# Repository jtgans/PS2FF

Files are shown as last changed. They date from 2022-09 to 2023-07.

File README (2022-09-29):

This is a simple board to handle exposing of the modern IBM PS/2 media sense
floppy disk controller such that it can be faked out on the controller side.

IOW, FlashFloppy (and by extension Gotek flash-based floppy drives) currently
cannot handle the advanced media sensing back to the PS/2 host controller. This
adapter exposes those media sense pins so that we can "fake" the media report
type to the host controller.

The board has been fabbed via OshPark, and is available here:
https://oshpark.com/shared_projects/WMa6Bw9U

The BoM was picked from DigiKey parts, and is available here:
http://www.digikey.com/short/2n20v9zv

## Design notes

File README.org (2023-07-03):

* PS/2 to FlashFloppy Media Sense Adapter

NOTE: This is still under development and does not work. Please don't assemble until revision C.

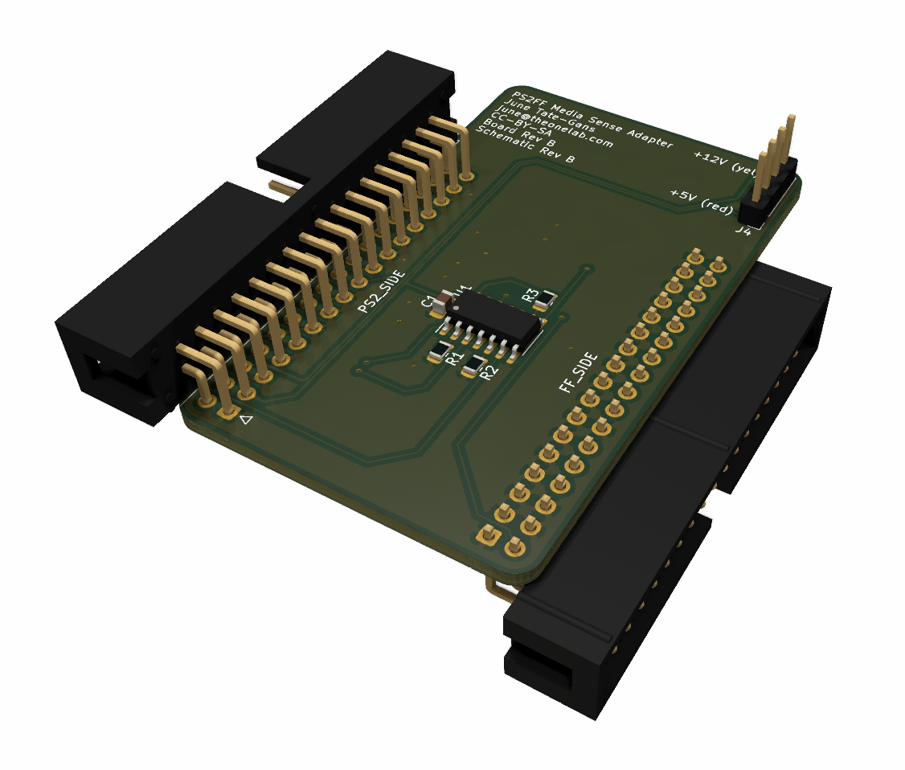
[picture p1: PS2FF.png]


This is a simple board to handle exposing of the modern IBM PS/2 media sense
floppy disk controller such that it can be faked out on the controller side.

IOW, FlashFloppy (and by extension Gotek flash-based floppy drives) currently
cannot handle the advanced media sensing back to the PS/2 host controller. This
adapter exposes those media sense pins so that we can "fake" the media report
type to the host controller.

The board has been fabbed via OshPark, and is available here:
https://oshpark.com/shared_projects/C5xEJw8V

The BoM was picked from DigiKey parts, and is available here:
https://www.digikey.com/short/q1v7w5mt

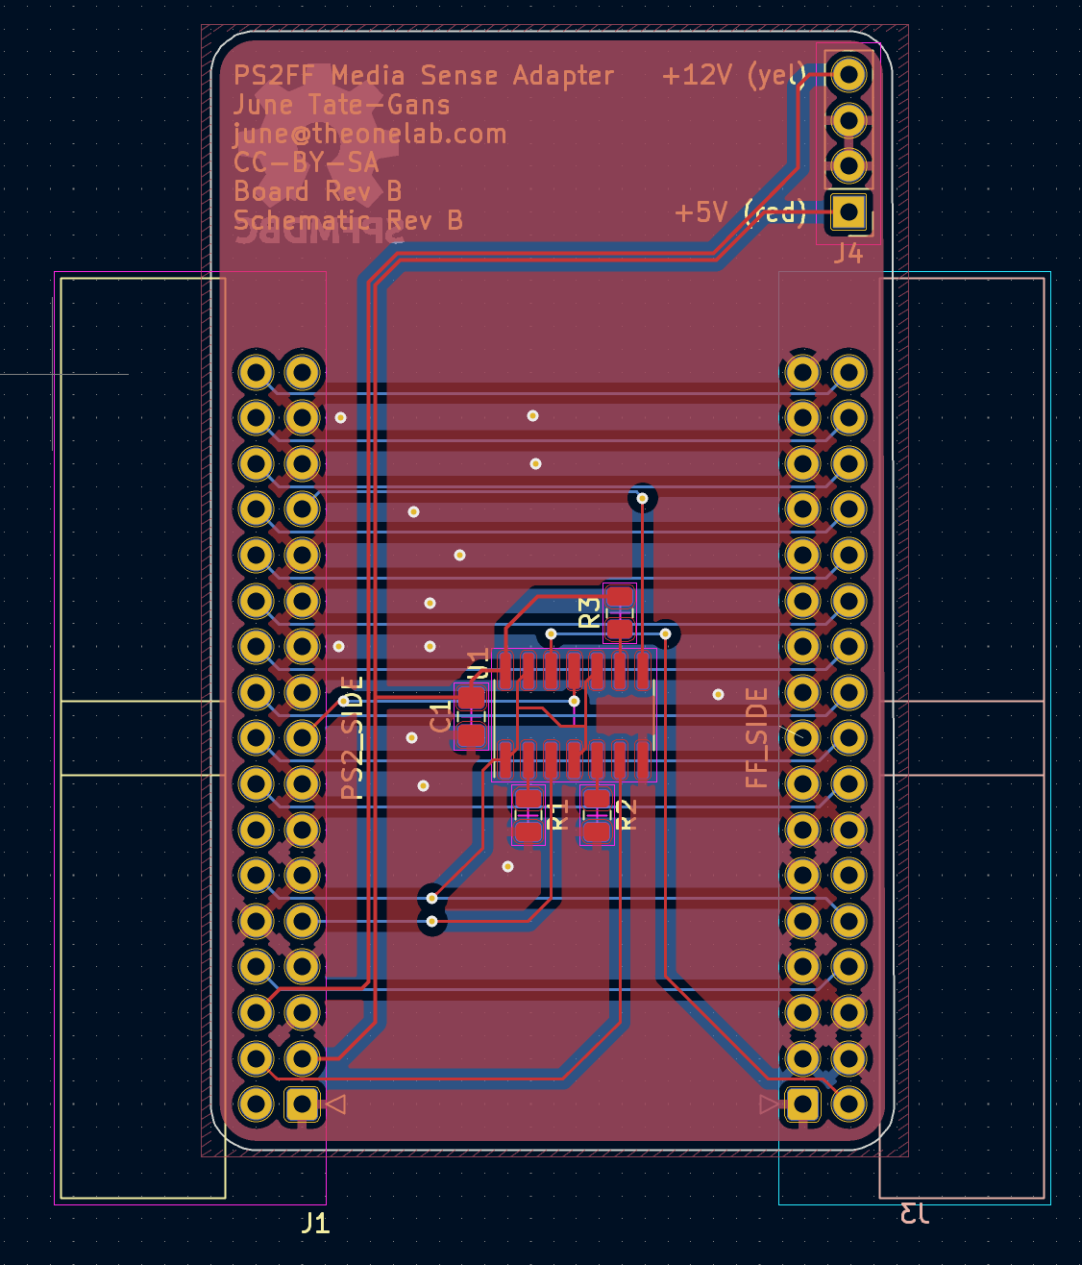
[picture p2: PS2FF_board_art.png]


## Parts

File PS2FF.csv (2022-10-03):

Source: | /Users/jtgans/Documents/Boards/PS2FF/PS2FF.kicad_sch
Date: | Monday, October 03, 2022 at 02:14:18 PM
Tool: | Eeschema (6.0.7-1)-1
Generator: | /Applications/KiCad/KiCad.app/Contents/SharedSupport/plugins/bom_csv_grouped_by_value_with_fp.py
Component Count: | 8
Ref | Qnty | Value | Cmp name | Footprint | Description | Vendor
C1, | 1 | 10pF | C_Small | Capacitor_SMD:C_0805_2012Metric_Pad1.18x1.45mm_HandSolder | Unpolarized capacitor, small symbol
J1, | 1 | PS2_SIDE | Conn_02x17_Odd_Even_1 | Connector_IDC:IDC-Header_2x17_P2.54mm_Horizontal | Generic connector, double row, 02x17, odd/even pin numbering scheme (row 1 odd numbers, row 2 even numbers), script generated (kicad-library-utils/schlib/autogen/connector/)
J3, | 1 | FF_SIDE | Conn_02x17_Odd_Even | Connector_IDC:IDC-Header_2x17_P2.54mm_Horizontal | Generic connector, double row, 02x17, odd/even pin numbering scheme (row 1 odd numbers, row 2 even numbers), script generated (kicad-library-utils/schlib/autogen/connector/)
J4, | 1 | POWER | Conn_01x04 | Connector_PinHeader_2.54mm:PinHeader_1x04_P2.54mm_Vertical | Generic connector, single row, 01x04, script generated (kicad-library-utils/schlib/autogen/connector/)
R1, R2, R3, | 3 | 1K | R_Small_US | Resistor_SMD:R_0805_2012Metric | Resistor, small US symbol
U1, | 1 | 74LS125 | 74LS125 | Package_SO:SOIC-14_3.9x8.7mm_P1.27mm | Quad buffer 3-State outputs

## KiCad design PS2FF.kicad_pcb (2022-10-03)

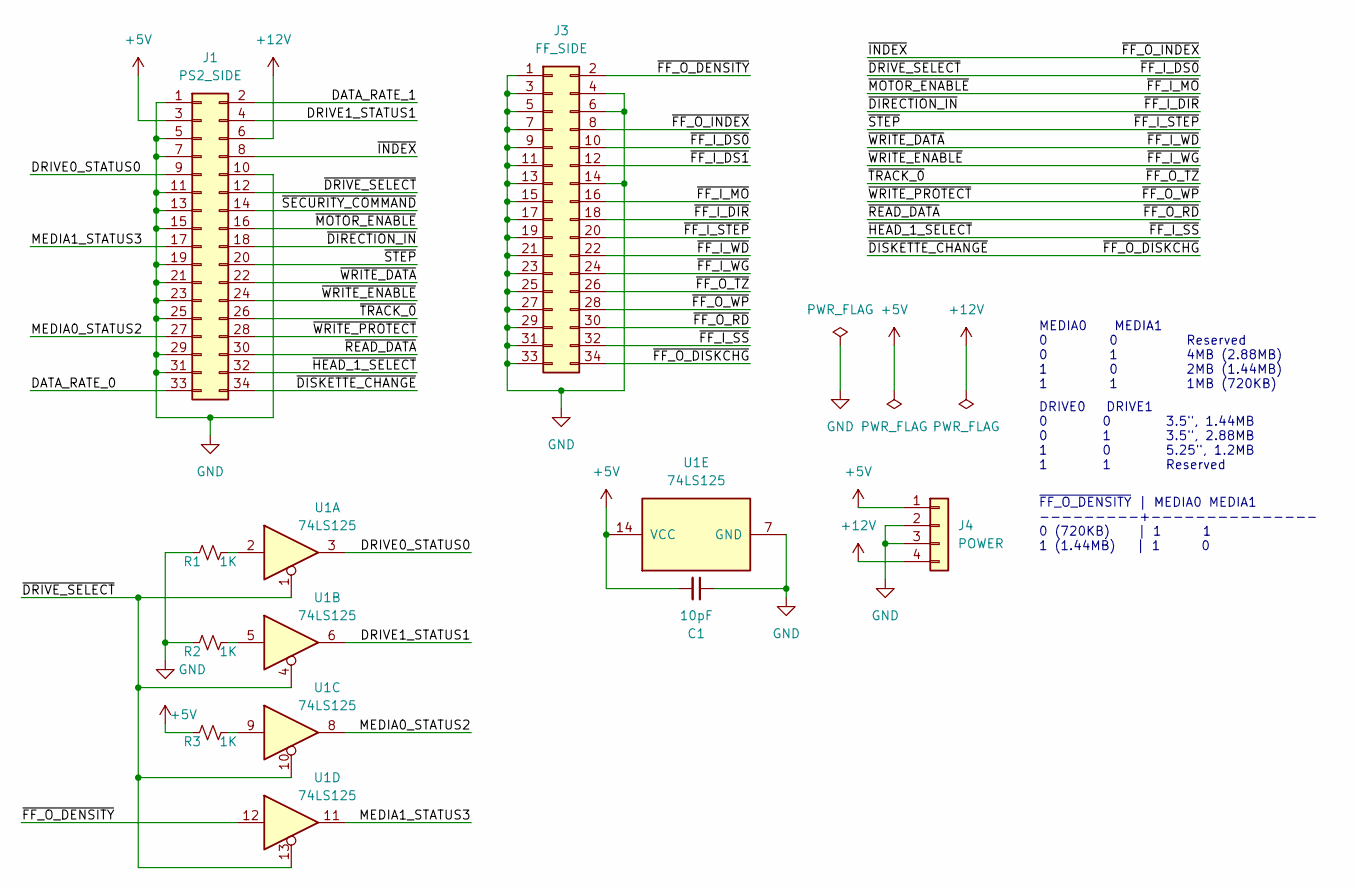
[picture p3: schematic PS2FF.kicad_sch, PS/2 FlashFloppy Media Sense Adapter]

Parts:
C1: 10pF; C_0805_2012Metric_Pad1.18x1.45mm_HandSolder
J1: PS2_SIDE; IDC-Header_2x17_P2.54mm_Horizontal
J3: FF_SIDE; IDC-Header_2x17_P2.54mm_Horizontal
J4: POWER; PinHeader_1x04_P2.54mm_Vertical
R1, R2, R3: 1K; R_0805_2012Metric
U1: 74LS125; SOIC-14_3.9x8.7mm_P1.27mm

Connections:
+5V: C1.2, J1.3, J4.1, R3.2, U1.14 (VCC)
+12V: J1.6, J4.4
/DATA_RATE_0: J1.33
/DATA_RATE_1: J1.2
/DRIVE0_STATUS0: J1.9, U1.3
/DRIVE1_STATUS1: J1.4, U1.6
/MEDIA0_STATUS2: J1.27, U1.8
/MEDIA1_STATUS3: J1.17, U1.11
/~DIRECTION_IN: J1.18, J3.18
/~DISKETTE_CHANGE: J1.34, J3.34
/~DRIVE_SELECT: J1.12, J3.10, U1.1, U1.4, U1.10, U1.13
/~FF_I_DS1: J3.12
/~FF_I_MO: J1.16, J3.16
/~FF_I_SS: J1.32, J3.32
/~FF_I_STEP: J1.20, J3.20
/~FF_I_WD: J1.22, J3.22
/~FF_I_WG: J1.24, J3.24
/~FF_O_DENSITY: J3.2, U1.12
/~FF_O_INDEX: J1.8, J3.8
/~FF_O_RD: J1.30, J3.30
/~FF_O_TZ: J1.26, J3.26
/~FF_O_WP: J1.28, J3.28
/~SECURITY_COMMAND: J1.14
GND: C1.1, J1.1, J1.5, J1.7, J1.10, J1.11, J1.13, J1.15, J1.19, J1.21, J1.23, J1.25, J1.29, J1.31, J3.1, J3.3, J3.4, J3.5, J3.6, J3.7, J3.9, J3.11, J3.13, J3.14, J3.15, J3.17, J3.19, J3.21, J3.23, J3.25, J3.27, J3.29, J3.31, J3.33, J4.2, J4.3, R1.2, R2.2, U1.7 (GND)
unnamed: R1.1, U1.2
unnamed: R2.1, U1.5
unnamed: R3.1, U1.9

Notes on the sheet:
DRIVE0 DRIVE1 0 0 3.5", 1.44MB 0 1 3.5", 2.88MB 1 0 5.25", 1.2MB 1 1 Reserved
MEDIA0 MEDIA1 0 0 Reserved 0 1 4MB (2.88MB) 1 0 2MB (1.44MB) 1 1 1MB (720KB)
~{FF_O_DENSITY} | MEDIA0 MEDIA1 ---------+--------------- 0 (720KB) | 1 1 1 (1.44MB) | 1 0

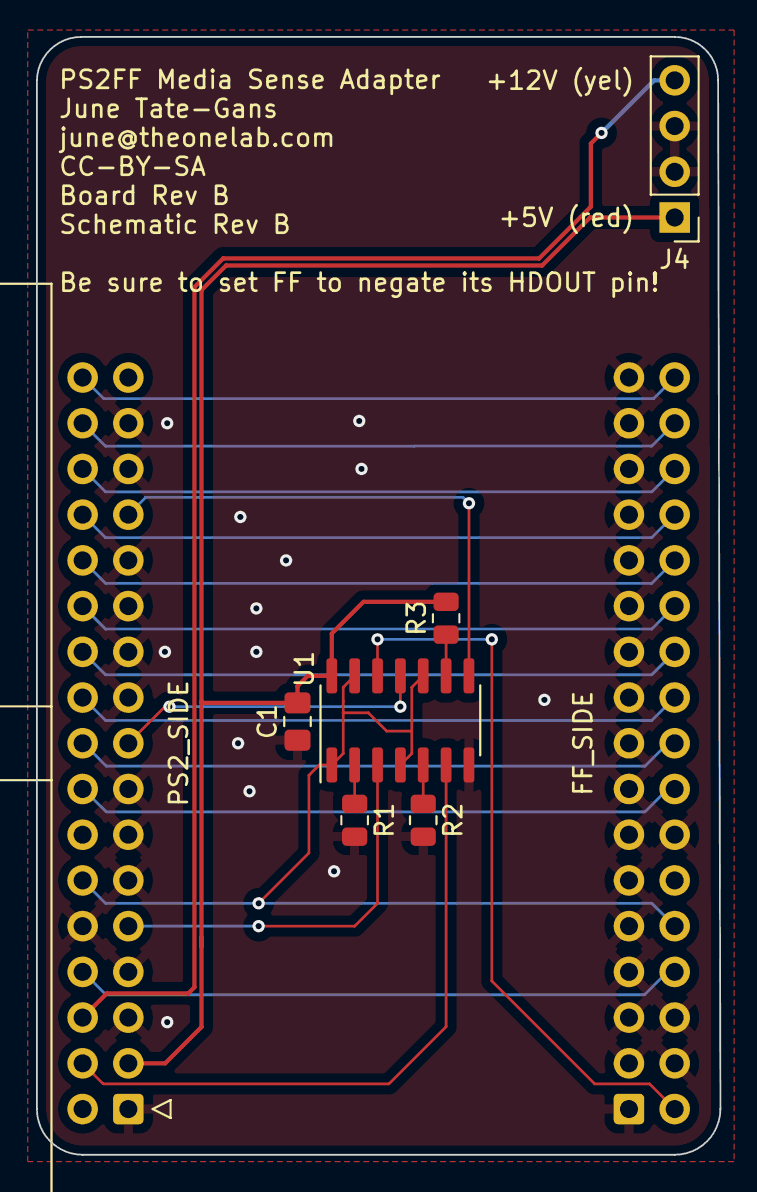
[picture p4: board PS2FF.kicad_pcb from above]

Board: 2 copper layers, 38.0 x 62.1 mm, 8 parts (1 on the bottom side), 23 nets.

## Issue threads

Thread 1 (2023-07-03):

Not working

Nephrite-FM, 2023-07-03:
I have tried to assemble this, however it is not working correctly.  When inserted the drive isn't recognized at all.

I'll try putting together another board, and I notice that you do not indicate on the board the orientation of the 74LS125.

Is there any news on Revision 3?

jtgans, 2023-07-03:
Ah, apologies. Yeah, it's not working right. My next steps are to attach my network analyzer to the bus and figure out the timing diagrams.

jtgans, 2023-07-03:
Didn't mean to close this.

Revision 3 is under development, been on hold until I can get back to it. Ran out of time with VCFSW, so that had to take priority. Will probably return to this very soon.

jtgans, 2023-07-03:
Orientation of the 74LS125 is using KiCad's braindead silk screen patterning, so use that as your guide.

jtgans, 2023-12-04:
Yeah, I'm not sure what that guy is selling, TBH. The photos of the board layout on PCBWay show a Q1 -- possibly a transistor or an LDO in there or something. None of my board revisions have that anywhere in the design. Weird that he's essentially copied my revision scheme and many of my texts in the silks -- guess he used mine as something to base his off of.

I think we can call this parallel invention. I don't see any particular problems here. His use case is different as well. I wanted the PS2FF to be an extension of the Gotek to allow it to report density properly to the host controller, whereas his is a fixed density report to the machine.

No, the reason mine doesn't work is because, well, it just _doesn't work_. In the prototypes I've built up, it makes my Model 77 think it has a 360KB 5.25" floppy drive attached. There's a sequencing problem going on in my 77 that makes it misunderstand what is attached. It's going to take some examination of the timings for multiple signals to figure this out. I'll see if I can maybe get some time on my Saleae today.

SudosFTW, 2023-12-04:
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

Ah, it looked almost like a direct copy but I'm 100% sure it's not now after following some of the traces from the 74LS125 to where they go. the one on their board is absolutely wired up differently. the PCBWay board is indeed a newer revision with what might be a transistor, not sure myself. I don't have an account with them to go and check the BOM. The jumper for straight-through and inversion is also a questionable addition I'm unsure of...

but it's a race to be first for full functionality I guess. you're one of three I now know working on such an adapter, seems eBay user Markgm is also supposedly working on such a design, or has at least stated it on another listing that one is "coming soon", but I don't know when that was placed there.

In my case, 35/40 are ISA machines like the 25/30 before it and might be able to use the one on eBay/pcbway but eh.
but anything below model 50 is ISA while 50 and above are all MCA, for the record. ISA machines have a starter disk that does not require ADF files, just plug and go like any normal PC. They also handle the floppies a bit differently at boot for that reason, but the 35/40 were definitely supporting of the 2.88MB drives.

As far as timings, might be an idea to try using the HCT part instead of the LS part instead? Also has the benefit of being a cheaper part, as LS 7400 chips are starting to get rather expensive. I know some things with older machines like the XT-IDE board don't like HCT parts for some of the logic (as told to me in person by glitchwrks at VCF East a couple years back), but I doubt it'll be any issue with floppy. in fact I'm sure the LS part is more than fast enough... but testing HCT part compatibility may help in the diagnostic stage while it's still being questioned.

vibr77, 2024-03-08:
Based on your very good work, I made this one that is working, I hope it will help others, I think we can change the 74LS125 by a 74LS245 that is a  2 channels OCTAL Bus buffer. https://github.com/vibr77/PS2FloppyDiskAdapterWMediaSense/

jtgans, 2024-03-08:
Looks like you took that repo private?

jtgans, 2024-03-08:
Also, why would we want to use an octal bus buffer instead of a quad? IIRC, we only care about two lines here.

vibr77, 2024-03-08:
> Looks like you took that repo private, or at least it doesn't exist yet. What did you change to make it work?

My mistake, should be visible

jtgans, 2024-03-08:
Wait, where are the actual source files? All you have there are PNGs and gerbers...

vibr77, 2024-03-08:
It is EasyEDA files for the PCB and the schema
It is at the root of the repo

jtgans, 2024-03-08:
Also, what's the fix here? You've totally redrawn the schematic. Looks like all you've done is add a transistor to invert the HDOUT pin from the flashfloppy -- is that the only change you made, because I was relying on the flashfloppy firmware to do that part.

vibr77, 2024-03-08:
Actually, I did only took the idea tu put the 74LS125, I did not check in details your design, and I add a transistor to to invert the HDOUT indeed. This is working like a charm

jtgans, 2024-03-08:
You're also testing on a model 55, which I think can be faked out with a single switch and a diode. It's nowhere near as complex as the later media sense controllers are, so I suspect this circuit won't work on a 77 or later machine.

Do you normally short JP2 in your use? Because that's the only thing I'm not doing in my schematic.

jtgans, 2024-03-08:
Ah, yeah, apologies. Model 57, not 55.

I'm going to have to study this more. It's not obvious why yours works and mine doesn't, if JP2 is not shorted when you do your testing. The wiring is identical in that case, aside from the inversion of the HDOUT pin from the flashfloppy. I'm assuming you're leaving JP1 shorted on pins 1 and 2?

vibr77, 2024-03-08:
yes between 1 and 2,
do you want my the jumper config of my GOTEK ?

jtgans, 2024-03-08:
Yes, that would be really helpful, actually! Yeah, maybe I had a software misconfiguration, then, because the only thing I can see different here is that you're just inverting HDOUT.

jtgans, 2024-03-08:
Bah. I can't use EasyEDA because their interface won't send me an activation email.

vibr77, 2024-03-08:
JC and S1 are shorted

jtgans, 2024-03-08:
Okay, so if JC is shorted, what's your FF.CFG say? Are you setting interface = jc or interface = ibmpc?

vibr77, 2024-03-08:
Interface = jc

From: June Tate-Gans ***@***.***>
Reply to: jtgans/PS2FF ***@***.***>
Date: Friday 8 March 2024 at 15:30
To: jtgans/PS2FF ***@***.***>
Cc: Vincent BESSON ***@***.***>, Comment ***@***.***>
Subject: Re: [jtgans/PS2FF] Not working (Issue #1)

Okay, so if JC is shorted, what's your FF.CFG say? Are you setting interface = jc or interface = ibmpc?

—
Reply to this email directly, view it on GitHub<https://github.com/jtgans/PS2FF/issues/1#issuecomment-1985794230>, or unsubscribe<https://github.com/notifications/unsubscribe-auth/A4ZT7FIH2SQNTMUWGRN77RDYXHDPDAVCNFSM6AAAAAAZ4R6NHWVHI2DSMVQWIX3LMV43OSLTON2WKQ3PNVWWK3TUHMYTSOBVG44TIMRTGA>.
You are receiving this because you commented.Message ID: ***@***.***>

jtgans, 2024-03-08:
According to https://github.com/keirf/flashfloppy/wiki/FF.CFG-Configuration-File#options if you're using the default FF.CFG, then shorting JC just sets the interface type to `ibmpc`, which leaves pin 2 (HDOUT) low all the time. In the Gotek schematics, it's just driving that signal through a FET which will effectively leave that pin floating if HDOUT is high. In your design, you're effectively always driving that pin before it goes through the transciever. In my design I'm using the pin raw off the FF, which could be floating in the high density case, which would end up indeterminate.

jtgans, 2024-03-08:
So the reason why yours works is actually because that pin is always being driven low. I'll bet if you set your FF.CFG `interface = ibmpc-hdout`, you'll get different results.

jtgans, 2024-03-08:
Nope, I'm wrong and missed the pullup on the Gotek. So in my schematic as long as you have `pin02 = ndens` set somewhere in your FF.CFG, the circuit should behave the same way. More digging required.

jtgans, 2024-03-08:
The more I read, the more I'm thinking your 57 is more tolerant to this schematic than my 77. I'll dig out my board and 77 and 90XP and see what I can see today.

vibr77, 2024-03-08:
pin02 is auto

From: June Tate-Gans ***@***.***>
Reply to: jtgans/PS2FF ***@***.***>
Date: Friday 8 March 2024 at 15:48
To: jtgans/PS2FF ***@***.***>
Cc: Vincent BESSON ***@***.***>, Comment ***@***.***>
Subject: Re: [jtgans/PS2FF] Not working (Issue #1)

Nope, I'm wrong and missed the pullup on the Gotek. So in my schematic as long as you have pin02 = ndens set somewhere in your FF.CFG, the circuit should behave the same way. More digging required.

—
Reply to this email directly, view it on GitHub<https://github.com/jtgans/PS2FF/issues/1#issuecomment-1985825351>, or unsubscribe<https://github.com/notifications/unsubscribe-auth/A4ZT7FPR7AKJWWJTNNJ22CDYXHFSNAVCNFSM6AAAAAAZ4R6NHWVHI2DSMVQWIX3LMV43OSLTON2WKQ3PNVWWK3TUHMYTSOBVHAZDKMZVGE>.
You are receiving this because you commented.Message ID: ***@***.***>

jtgans, 2024-03-08:
I didn't need to. It's controlled with software.

vibr77, 2024-03-08:
hum... I would give it a try just to check... trusting soft could sometimes leads to ...

jtgans, 2024-03-08:
I've read through the software. It shouldn't matter, and definitely shouldn't be causing the issue I was seeing w.r.t. the system mis-identifying the drive as a 1.2MB 5.25" floppy drive.

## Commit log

2022-09-29 first commit: Import revision A of the schematic and board
    [PS2FF.csv, PS2FF.kicad_pcb, PS2FF.kicad_sch]
2022-09-29 readme: Add in a board rendering
2022-09-29 readme: add in some board art images
2022-09-30 Fix up some DRC errors in the schematic
    [PS2FF.kicad_pcb, PS2FF.kicad_sch]
2022-09-30 Bump the board rev since new changes
    [PS2FF.kicad_pcb, PS2FF.kicad_sch]
2022-10-03 automate things: Swap to using a buffer to automate
    - Use a simple buffer to drive outputs to the host side.
    - Wire in FF_O_DENSITY to the appropriate pin via the buffers.
    Note: this requires FF to be set to invert this output!
    [PS2FF.csv, PS2FF.kicad_pcb, PS2FF.kicad_sch]
2022-10-03 silks: Add a note about the hdout pin
    [PS2FF.kicad_pcb]
2022-10-03 writing: Actually wire up the HDOUT pin from the FF side
    Update the links with the rev B schematic/PCB for fab.
    [PS2FF.kicad_pcb]

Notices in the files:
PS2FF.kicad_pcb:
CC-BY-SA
